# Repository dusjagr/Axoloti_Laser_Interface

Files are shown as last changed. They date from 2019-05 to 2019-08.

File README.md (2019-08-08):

# Axoloti_Laser_Interface
Adding some special outputs to Axoloti to control a Laser projector. X-Y on audio, 3 RGB outputs on PWM

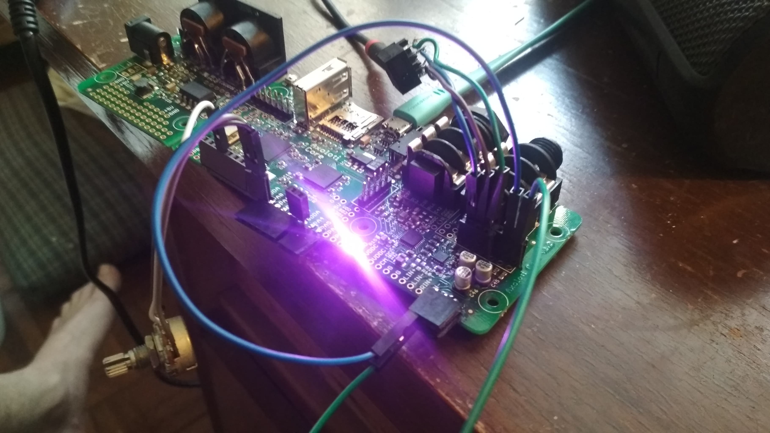
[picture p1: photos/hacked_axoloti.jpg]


# X-Y amplification stage

Which output should we use?

* Audio output from the Jack. L to X, and R to Z
* LOUT+ and LOUT- to have balanced signal directly

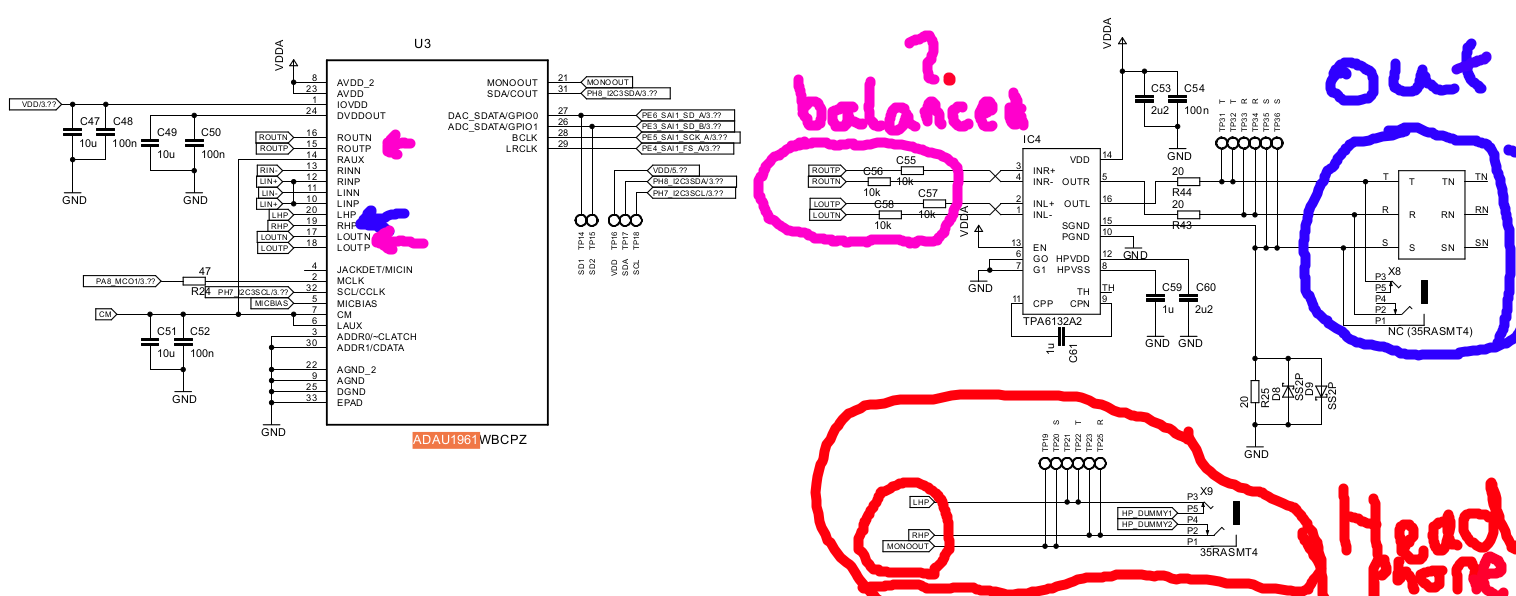
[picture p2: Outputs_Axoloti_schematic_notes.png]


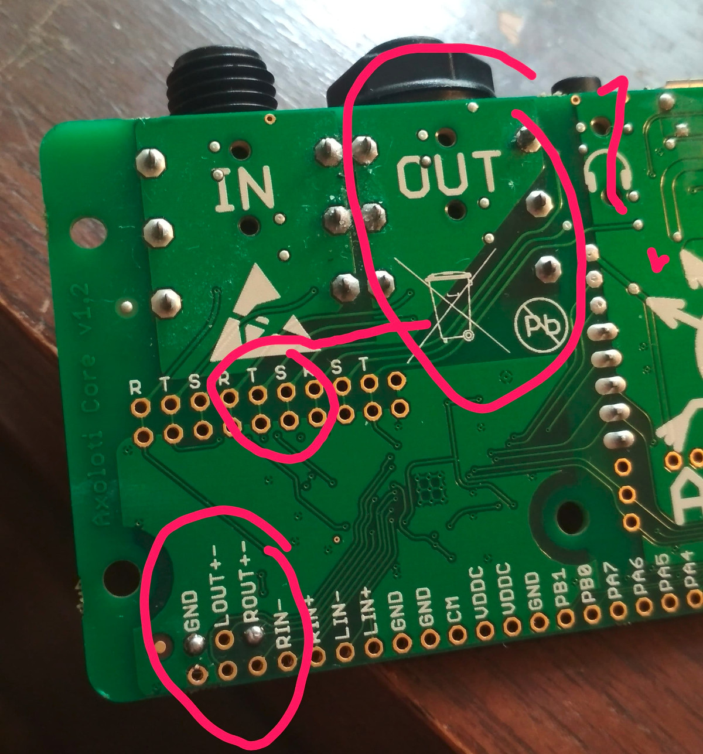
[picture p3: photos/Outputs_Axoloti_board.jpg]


## Amplifier

We need to go to +/- 5V to have maximum range

Easy with LM072 op-amp

## Balanced output

Seems we need balanced signals. ok. add another LM072 op-amp

## Schematic

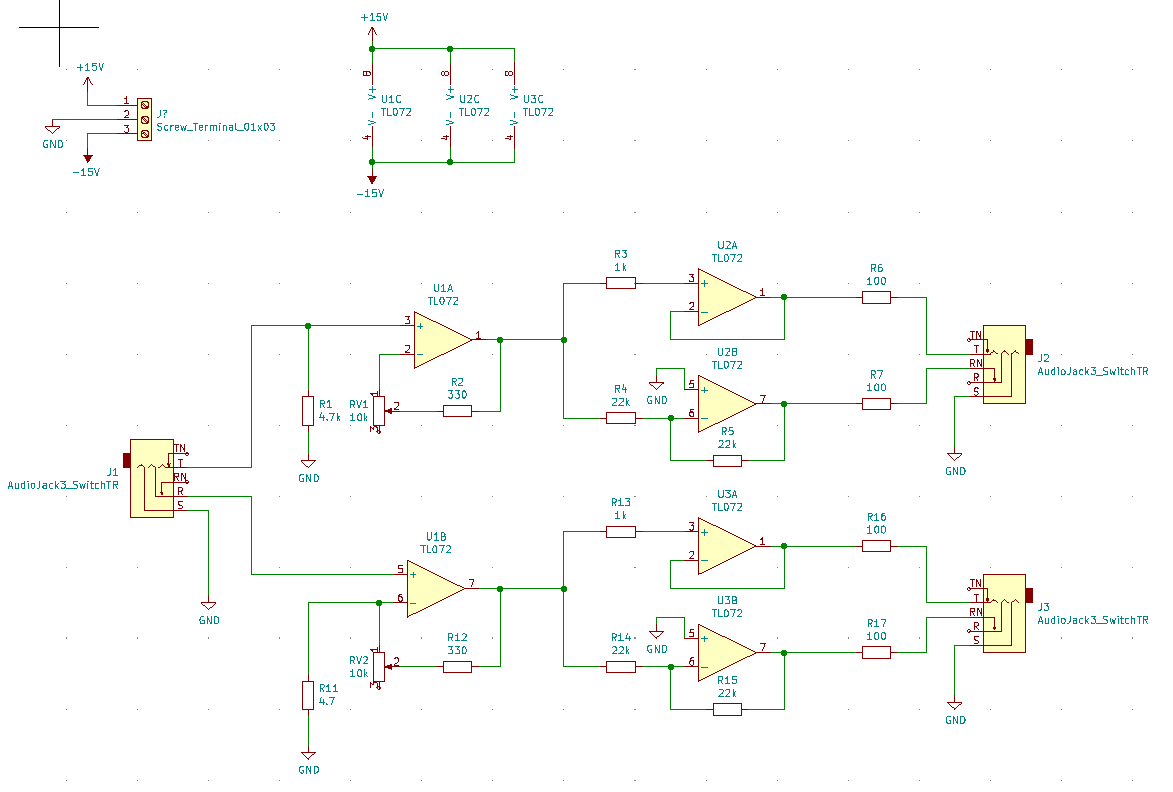
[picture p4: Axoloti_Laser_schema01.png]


# RGB output
## PWM?

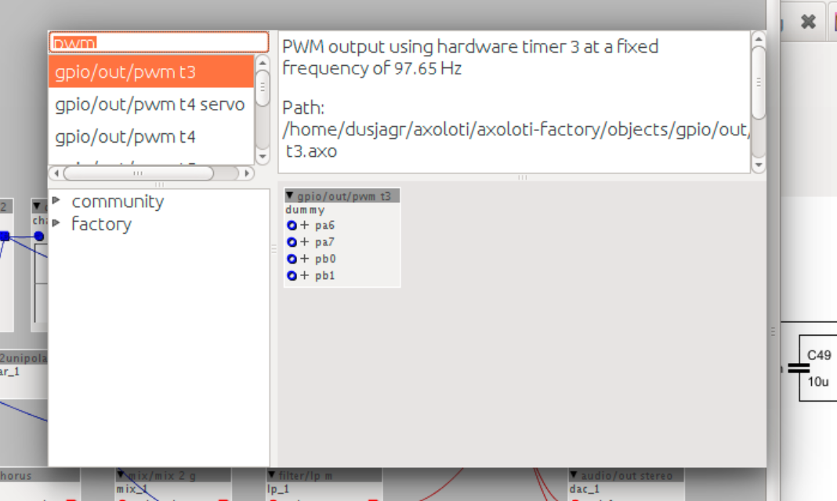
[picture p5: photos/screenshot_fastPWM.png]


## Filter and Amp needed?

# Axoloti Patch

http://community.axoloti.com/t/pwm-output-pin-frequency/2776/11

## Changing the PWM frequency and resolution:

static const PWMConfig pwmcfg = {400000, /* 400kHz PWM clock frequency.  */
	4096, /* PWM period is 4096 cycles.    */
	NULL, 
	{{PWM_OUTPUT_ACTIVE_HIGH, NULL}, 
	{PWM_OUTPUT_ACTIVE_HIGH, NULL},
	{PWM_OUTPUT_ACTIVE_HIGH, NULL}, 
	{PWM_OUTPUT_ACTIVE_HIGH, NULL}},
	/* HW dependent part.*/
	0};

pwmStart(&PWMD3, &pwmcfg);
  
palSetPadMode(GPIOA, 6, PAL_MODE_ALTERNATE(2));
palSetPadMode(GPIOA, 7, PAL_MODE_ALTERNATE(2));
palSetPadMode(GPIOB, 0, PAL_MODE_ALTERNATE(2));
palSetPadMode(GPIOB, 1, PAL_MODE_ALTERNATE(2));

# Further info

## Other Axoloty vector synths

https://www.akirasrebirth.com/

http://community.axoloti.com/t/axoloti-ilda-laser/5634/4

## Technical help

https://en.wikipedia.org/wiki/Balanced_audio

https://www.electronics-notes.com/articles/analogue_circuits/operational-amplifier-op-amp/non-inverting-amplifier.php

http://sound.whsites.net/project51.htm

https://github.com/ffd8/dac_ilda

## Other commercial hardware/Software

https://www.laserworld.com/shop/laserworld-shownet-network-interface

https://lzxindustries.net/products/cyclops

https://www.showeditor.com/en

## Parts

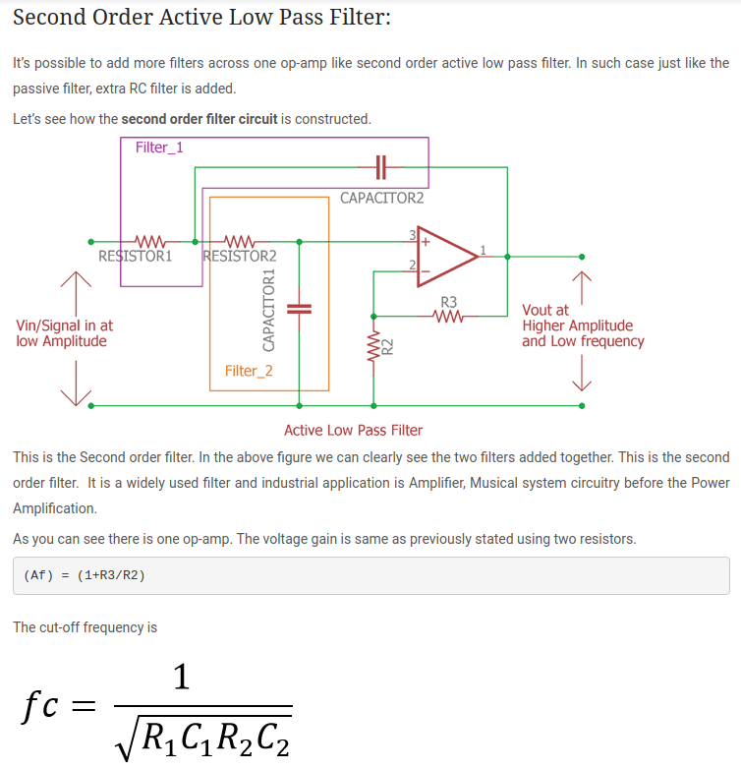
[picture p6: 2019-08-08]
photos/2ndOrder_LPF.png

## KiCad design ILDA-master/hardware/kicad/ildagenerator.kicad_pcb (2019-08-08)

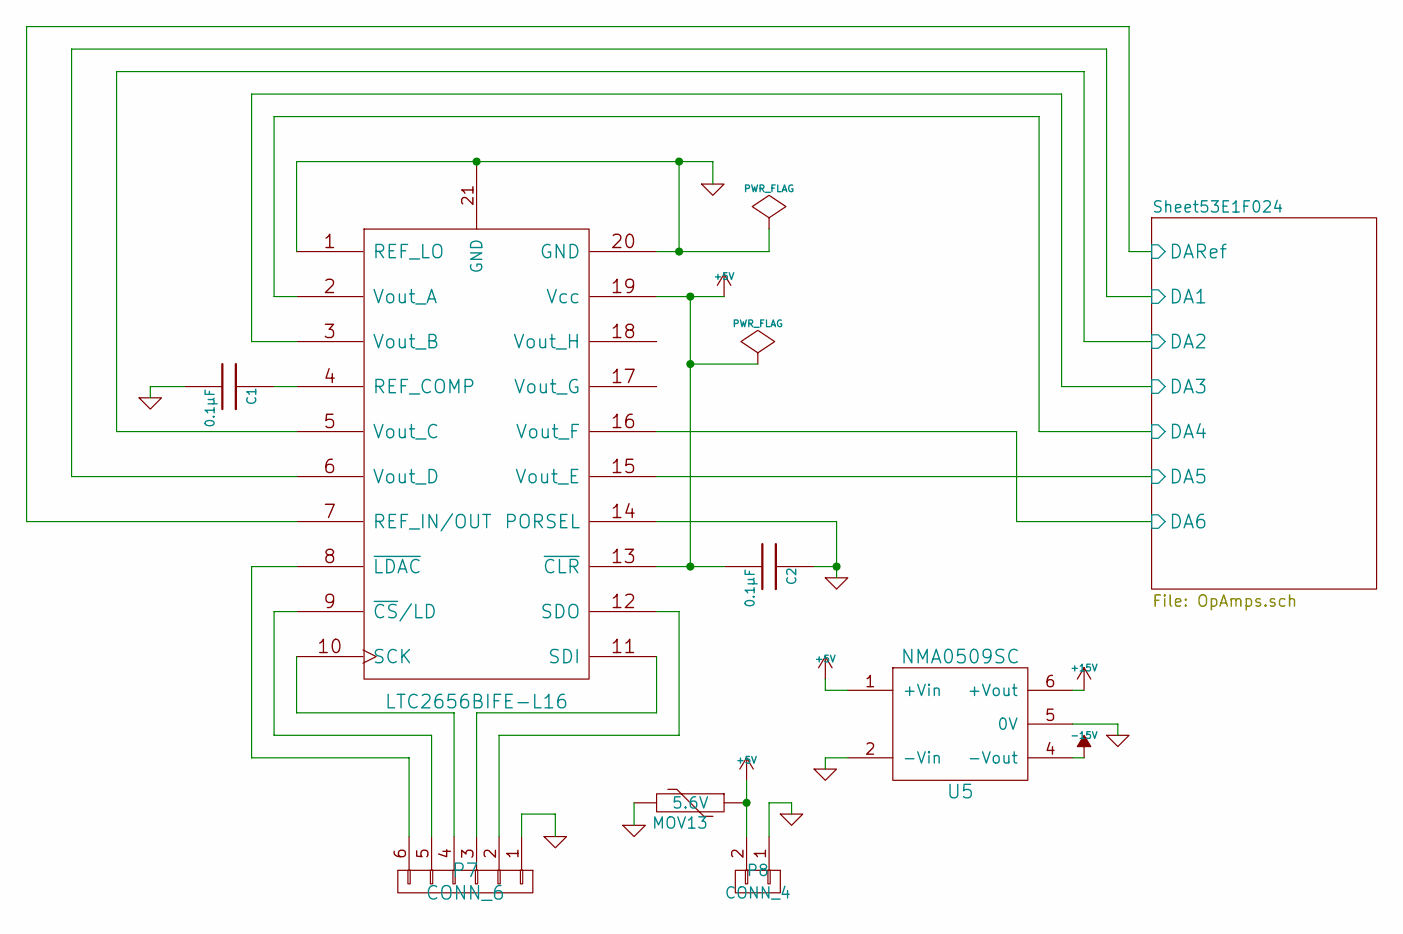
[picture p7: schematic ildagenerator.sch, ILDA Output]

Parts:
C1, C2: 0.1µF; C_0805_HandSoldering
MOV13: 5.6V; R_1206_HandSoldering
P7: CONN_6; Pin_Header_Straight_1x06
P8: CONN_4; Pin_Header_Straight_1x02
U1: LTC2656BIFE-L16
U5: NMA0509SC; NMA_5V_12V_15V_Series

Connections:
+5V: C2.2, MOV13.1, P8.2, U1.13 (~CLR), U1.19 (Vcc), U5.1 (+Vin)
+15V: U5.6 (+Vout); also elsewhere on the board
-15V: U5.4 (-Vout); also elsewhere on the board
/Sheet53E1F024/DA1: U1.6 (Vout_D); also elsewhere on the board
/Sheet53E1F024/DA2: U1.5 (Vout_C); also elsewhere on the board
/Sheet53E1F024/DA3: U1.3 (Vout_B); also elsewhere on the board
/Sheet53E1F024/DA4: U1.2 (Vout_A); also elsewhere on the board
/Sheet53E1F024/DA5: U1.15 (Vout_E); also elsewhere on the board
/Sheet53E1F024/DA6: U1.16 (Vout_F); also elsewhere on the board
/Sheet53E1F024/DARef: U1.7 (REF_IN/OUT); also elsewhere on the board
GND: C1.2, C2.1, MOV13.2, P7.1, P8.1, U1.1 (REF_LO), U1.14 (PORSEL), U1.20 (GND), U1.21 (GND), U5.2 (-Vin), U5.5 (0V); also elsewhere on the board
unnamed: C1.1, U1.4 (REF_COMP)
unnamed: P7.2, U1.12 (SDO)
unnamed: P7.3, U1.11 (SDI)
unnamed: P7.4, U1.10 (SCK)
unnamed: P7.5, U1.9 (~CS~/LD)
unnamed: P7.6, U1.8 (~LDAC)

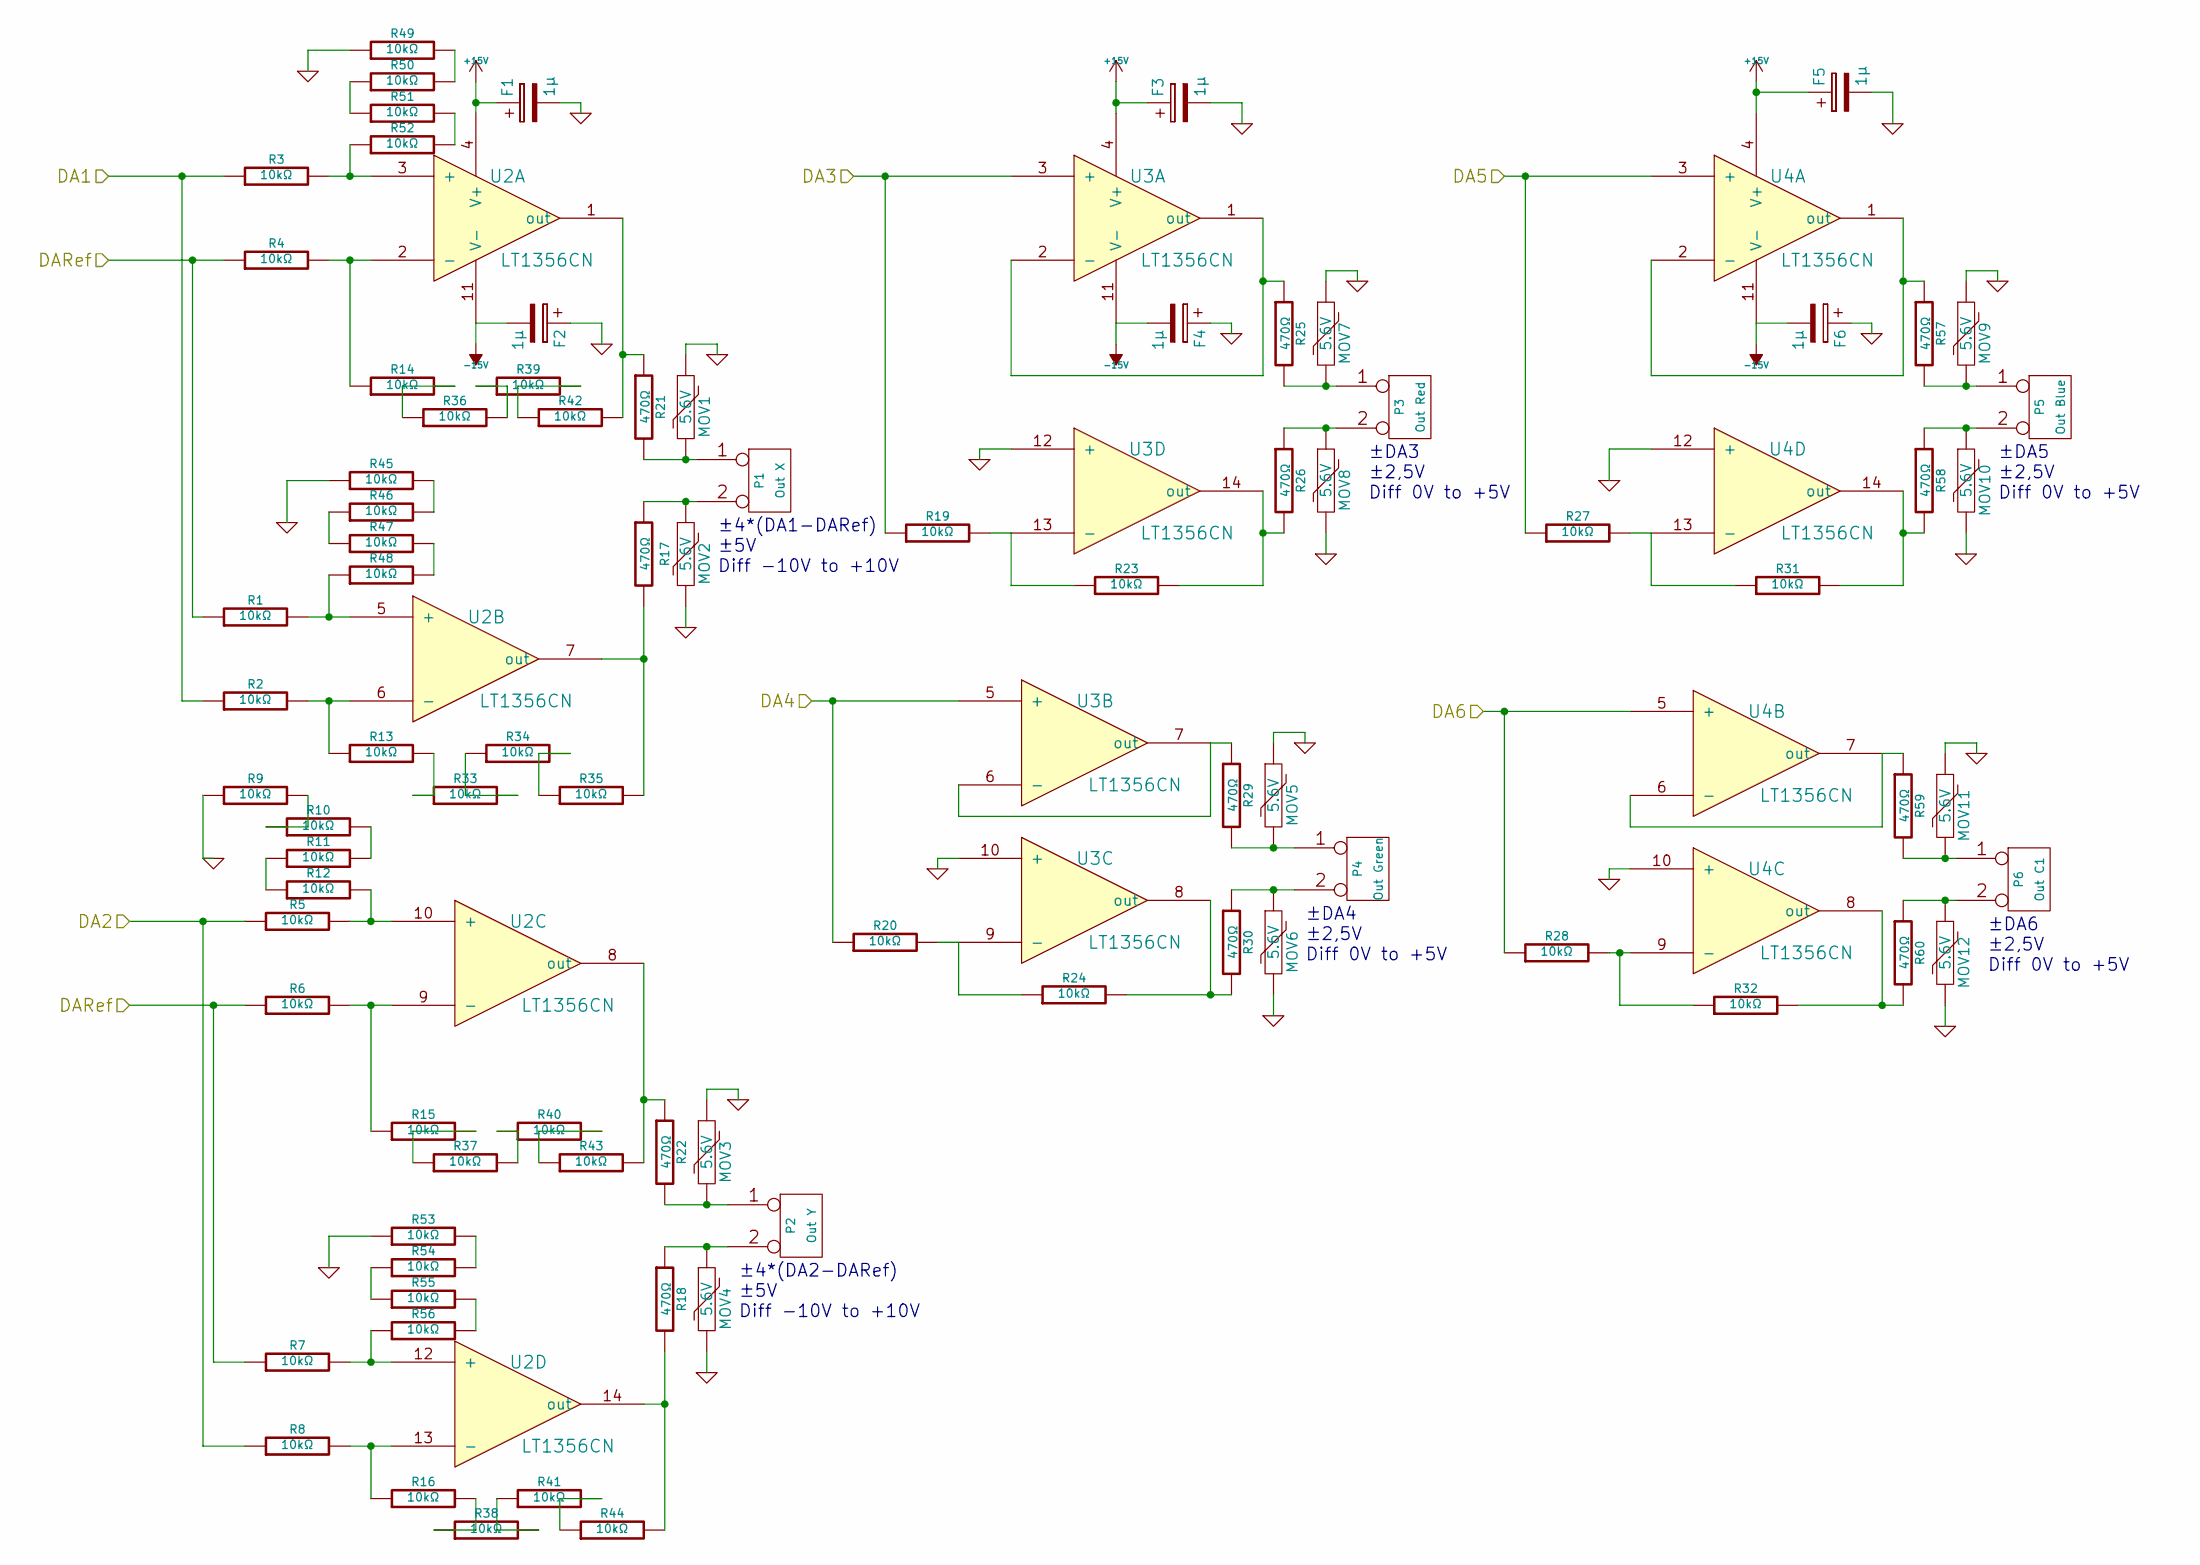
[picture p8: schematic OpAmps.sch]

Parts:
F1, F2, F3, F4, F5, F6: 1µ; TantalC_SizeB_EIA-3528_HandSoldering
MOV1, MOV2, MOV3, MOV4, MOV5, MOV6, MOV7, MOV8, MOV9, MOV10, MOV11, MOV12: 5.6V; R_1206_HandSoldering
P1: Out X
P2: Out Y
P3: Out Red
P4: Out Green
P5: Out Blue
P6: Out C1
R1, R2, R3, R4, R5, R6, R7, R8, R9, R10, R11, R12, R13, R14, R15, R16, R20, R24, R33, R34, R35, R36, R37, R38, R39, R40, R41, R42, R43, R44, R45, R46, R47, R48, R49, R50, R51, R52, R53, R54, R55, R56: 10kΩ; R_0603_HandSoldering
R17, R18, R21, R22: 470Ω; R_0603_HandSoldering
R19, R23, R27, R28, R31, R32: 10kΩ
R25, R26, R29, R30, R57, R58, R59, R60: 470Ω
U2, U3, U4: LT1356CN

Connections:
+15V: F1.1, F3.1, F5.1, U2.4 (V+), U3.4 (V+), U4.4 (V+); also elsewhere on the board
-15V: F2.2, F4.2, F6.2, U2.11 (V-), U3.11 (V-), U4.11 (V-); also elsewhere on the board
/Sheet53E1F024/DA1: R2.1, R3.1; also elsewhere on the board
/Sheet53E1F024/DA2: R5.1, R8.1; also elsewhere on the board
/Sheet53E1F024/DA3: R19.1, U3.3 (+); also elsewhere on the board
/Sheet53E1F024/DA4: R20.1, U3.5 (+); also elsewhere on the board
/Sheet53E1F024/DA5: R27.1, U4.3 (+); also elsewhere on the board
/Sheet53E1F024/DA6: R28.1, U4.5 (+); also elsewhere on the board
/Sheet53E1F024/DARef: R1.1, R4.1, R6.1, R7.1; also elsewhere on the board
GND: F1.2, F2.1, F3.2, F4.1, F5.2, F6.1, MOV1.1, MOV2.2, MOV3.1, MOV4.2, MOV5.1, MOV6.2, MOV7.1, MOV8.2, MOV9.1, MOV10.2, MOV11.1, MOV12.2, R9.1, R45.1, R49.1, R53.1, U3.10 (+), U3.12 (+), U4.10 (+), U4.12 (+); also elsewhere on the board
unnamed: MOV1.2, P1.1, R21.2
unnamed: MOV2.1, P1.2 (PM), R17.1
unnamed: MOV3.2, P2.1, R22.2
unnamed: MOV4.1, P2.2 (PM), R18.1
unnamed: MOV5.2, P4.1, R29.2
unnamed: MOV6.1, P4.2 (PM), R30.1
unnamed: MOV7.2, P3.1, R25.2
unnamed: MOV8.1, P3.2 (PM), R26.1
unnamed: MOV9.2, P5.1, R57.2
unnamed: MOV10.1, P5.2 (PM), R58.1
unnamed: MOV11.2, P6.1, R59.2
unnamed: MOV12.1, P6.2 (PM), R60.1
unnamed: R1.2, R48.1, U2.5 (+)
unnamed: R3.2, R52.1, U2.3 (+)
unnamed: R9.2, R10.1
unnamed: R10.2, R11.2
unnamed: R11.1, R12.1
unnamed: R5.2, R12.2, U2.10 (+)
unnamed: R2.2, R13.1, U2.6 (-)
unnamed: R13.2, R33.1
unnamed: R4.2, R14.1, U2.2 (-)
unnamed: R14.2, R36.1
unnamed: R6.2, R15.1, U2.9 (-)
unnamed: R15.2, R37.1
unnamed: R8.2, R16.1, U2.13 (-)
unnamed: R16.2, R38.1
unnamed: R17.2, R35.2, U2.7 (out)
unnamed: R18.2, R44.2, U2.14 (out)
unnamed: R19.2, R23.1, U3.13 (-)
unnamed: R20.2, R24.1, U3.9 (-)
unnamed: R21.1, R42.2, U2.1 (out)
unnamed: R22.1, R43.2, U2.8 (out)
unnamed: R23.2, R26.2, U3.14 (out)
unnamed: R24.2, R30.2, U3.8 (out)
unnamed: R25.1, U3.1 (out), U3.2 (-)
unnamed: R27.2, R31.1, U4.13 (-)
unnamed: R28.2, R32.1, U4.9 (-)
unnamed: R29.1, U3.6 (-), U3.7 (out)
unnamed: R31.2, R58.2, U4.14 (out)
unnamed: R32.2, R60.2, U4.8 (out)
unnamed: R33.2, R34.1
unnamed: R34.2, R35.1
unnamed: R36.2, R39.1
unnamed: R37.2, R40.1
unnamed: R38.2, R41.1
unnamed: R39.2, R42.1
unnamed: R40.2, R43.1
unnamed: R41.2, R44.1
unnamed: R45.2, R46.2
unnamed: R46.1, R47.1
unnamed: R47.2, R48.2
unnamed: R49.2, R50.2
unnamed: R50.1, R51.1
unnamed: R51.2, R52.2
unnamed: R53.2, R54.2
unnamed: R54.1, R55.1
unnamed: R55.2, R56.2
unnamed: R7.2, R56.1, U2.12 (+)
unnamed: R57.1, U4.1 (out), U4.2 (-)
unnamed: R59.1, U4.6 (-), U4.7 (out)

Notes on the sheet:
±4*(DA1-DARef) ±5V Diff -10V to +10V
±4*(DA2-DARef) ±5V Diff -10V to +10V
±DA3 ±2,5V Diff 0V to +5V
±DA4 ±2,5V Diff 0V to +5V
±DA5 ±2,5V Diff 0V to +5V
±DA6 ±2,5V Diff 0V to +5V

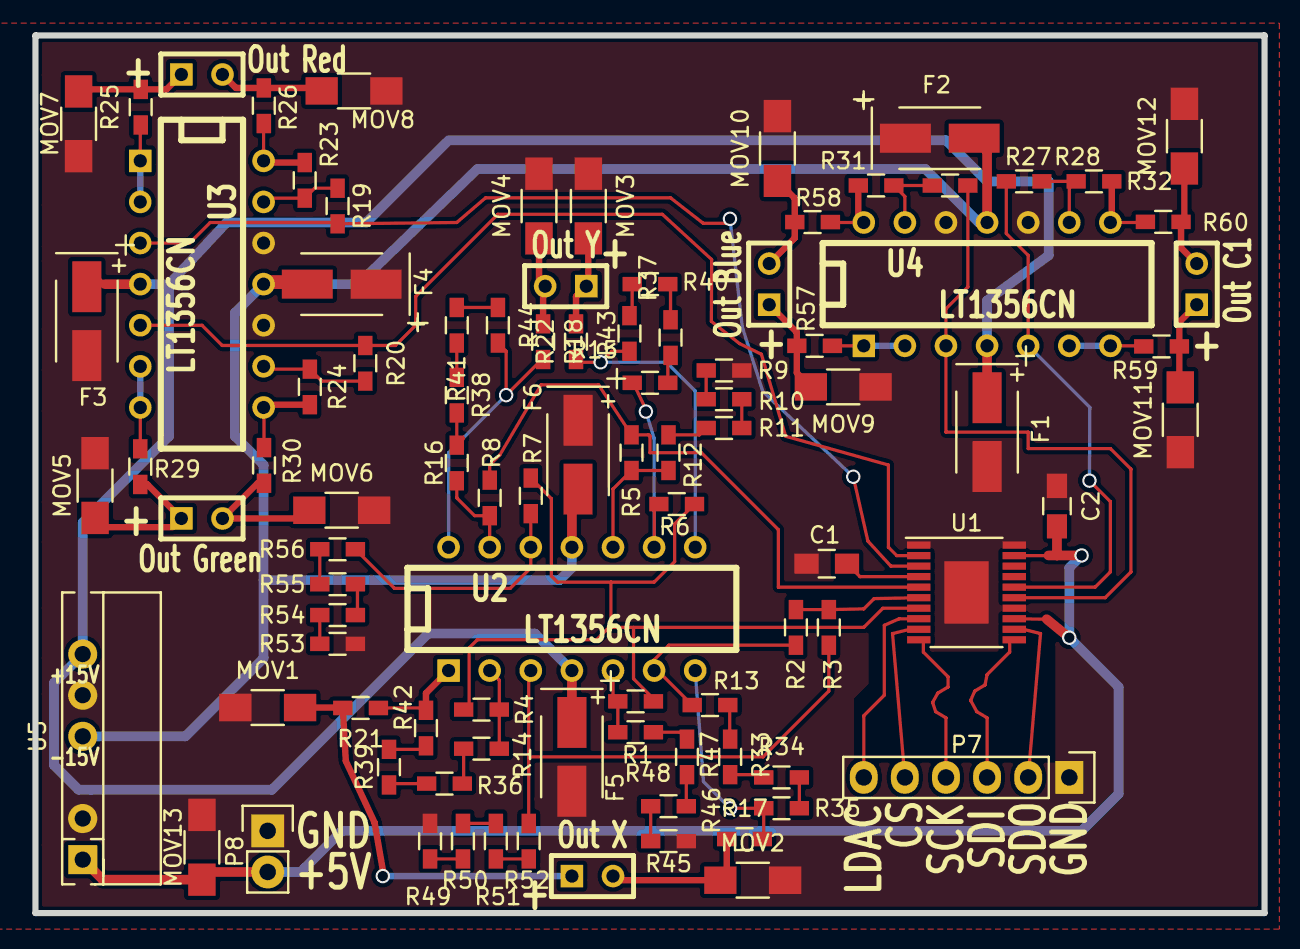
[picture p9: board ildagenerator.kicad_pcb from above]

Board: 2 copper layers, 75.9 x 54.2 mm, 94 parts (0 on the bottom side), 77 nets.

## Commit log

2019-05-13 first files, Kicad
    [AxolotiLaser.kicad_pcb, AxolotiLaser.sch]
2019-05-13 rearranging files
    [AxolotiLaser.kicad_pcb, AxolotiLaser.sch]
2019-08-08 minor fixes
    [AxolotiLaser.kicad_pcb, AxolotiLaser.sch, OpAmps-2019-05-14-12-13-00.sch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]
